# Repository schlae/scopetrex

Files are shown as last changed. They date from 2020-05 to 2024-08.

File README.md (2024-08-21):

# SCOPETREX
## Vector Gaming on Your Oscilloscope!

**Update 21-August-2024: I learned that the IRQ line on the 65C22 wasn't connected, so I fixed that.
See the section at the bottom for details, or just fab with the latest files and don't worry about it.**

Have you ever wanted to buy a Vectrex, but you can't afford the high prices on
auction sites? Do you already have a hoard of Vectrexes, but want *another*
one? Well now you can build your own!

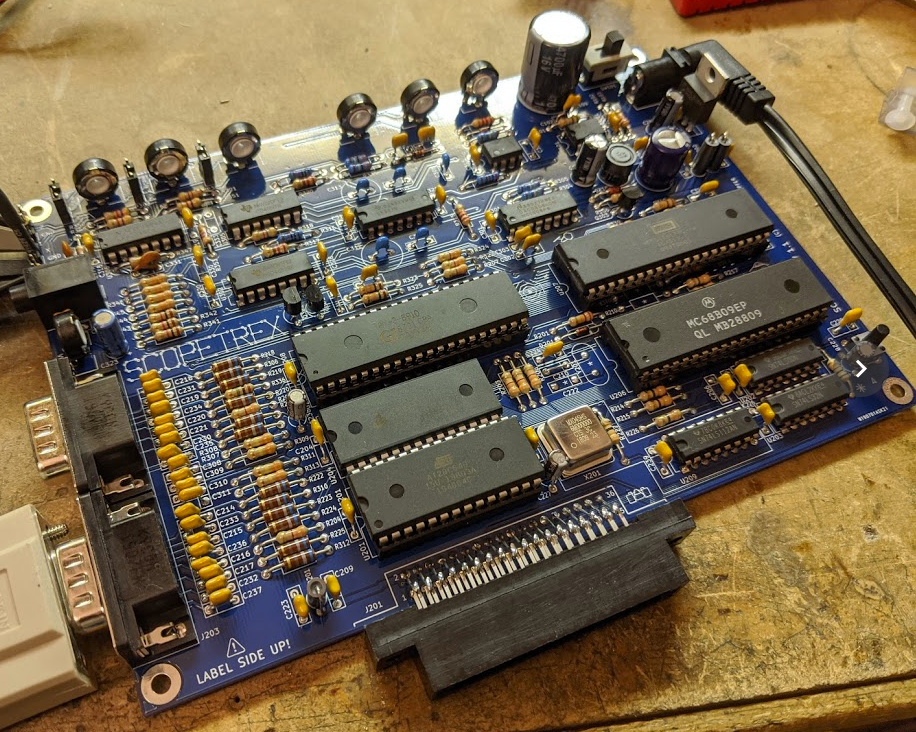
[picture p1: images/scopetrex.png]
SCOPETREX photo


The SCOPETREX is basically a Vectrex on a single board without a monitor.
To play games, you have to connect it to an oscilloscope or an XY monitor.

This board is not just an exact clone of a Vectrex; it makes a number of
improvements over the original.

* Single +5V power supply, only 500mA (minimum)
* Configurable X and Y size and polarity
* Configurable brightness and video blanking polarity
* Works with a 68A09/68B09 or the more common 68A09E/68B09E
* Works with the AY-3-8912 sound chip or the cheaper AY-3-8910/YM2149F
* Custom controller board which is also compatible with the Vectrex
* Cool art on the board

All of the components are readily available, either from Mouser or from
various brokers in China. The bills of materials include Mouser part numbers.

[Here is the schematic](https://github.com/schlae/scopetrex/blob/master/Scopetrex.pdf).

There are two separate bills of materials. One is configured for people who
wish to build their SCOPETREX with the 68A09/68B09 (no suffix option), and
the other is configured for the 68A09E/68B09E (note the **E** suffix). In
general, the **E** suffix is easier to find and it is less likely to be a
counterfeit part. One caution: the 6809 and 6809E (no A or B) chips are only
rated to 1MHz while the SCOPETREX requires 1.5MHz operation.

[Bill of Materials, 6809 (plain) version](https://github.com/schlae/scopetrex/blob/master/Scopetrex_6809.csv)

[Bill of Materials, 6809E version](https://github.com/schlae/scopetrex/blob/master/Scopetrex_6809E.csv)

Please note that the 0.1" header pins are *not* listed on the BOM. They are
just standard breakaway headers. Jumper shunts (you will need three) are also
not listed on the BOM.

The game cartridge slot is designed to be used with the Sullins EBC18DRAS
(listed in the BOM as S3311-ND) but you can also use the EDAC 395-036-520-202
since it is available from Mouser and it may be more convenient to order all
the parts at once. If you do this, you will need to install the EDAC slot
at a right angle and add 18 bodge wires (see the Assembly Notes section).

[Here are the fab files](https://github.com/schlae/scopetrex/blob/master/fab/Scopetrex.zip).

Board dimensions are 7 x 5 inches. Order the board in whatever cool colors
you like!

## The Controller
The SCOPETREX also has a controller.

[Schematic](https://github.com/schlae/scopetrex/blob/master/controller/controller.pdf)

[Bill of Materials](https://github.com/schlae/scopetrex/blob/master/controller/controller.csv)

[Fab files](https://github.com/schlae/scopetrex/blob/master/controller/fab/controller.zip)

The board is 5.8 x 2 inches. It's very simple, so before fabbing it out,
considering going into Kicad and customizing it to your tastes. Add some fancy
silkscreen artwork or whatever you want.

The thumb joystick is listed with a Digi-Key part number since Mouser doesn't
carry it, but you can also get it from [Sparkfun](https://www.sparkfun.com/products/9032). There are similar joysticks sold by a number of different vendors
but this is the only one that's been tested.

There is a slide switch with 4 positions that selects which button (1 through
4) the top hat control triggers (when you push down on the joystick).

## Firmware
The SCOPETREX will run with the standard Vectrex firmware. Just program it
into the flash memory chip (the AT28C64). Note that the "Vectrex BIOS" ROM that
you may find does not include the MINE STORM game. Often, the "MINE STORM" ROM
comes with the BIOS so you should use that instead. I will not tell you where
to get ROMs, nor will I send you any. You could go buy a broken Vectrex and
transplant the ROM from that.

## Assembly Notes

In general it is a good idea to socket the chips that are hard to find and
thus may be counterfeit. It makes troubleshooting much easier. Therefore,
consider socketing the 6809, the 65C22, and the AY-3-8910/12.

The U101/MC34063 power supply chip should be soldered directly to the board
for best performance since a socket adds resistance.

The game cartridge connector has two different part numbers on the BOM. If
you ordered the EDAC part from Mouser which is designed to mount vertically
on the board, you will not be able to plug the cart into it because the case
will bump into components on the board. I recommend rotating the connector
90 degrees and soldering the bottom 18 pins directly to the footprint and
connecting the top 18 pins using bodge wires.

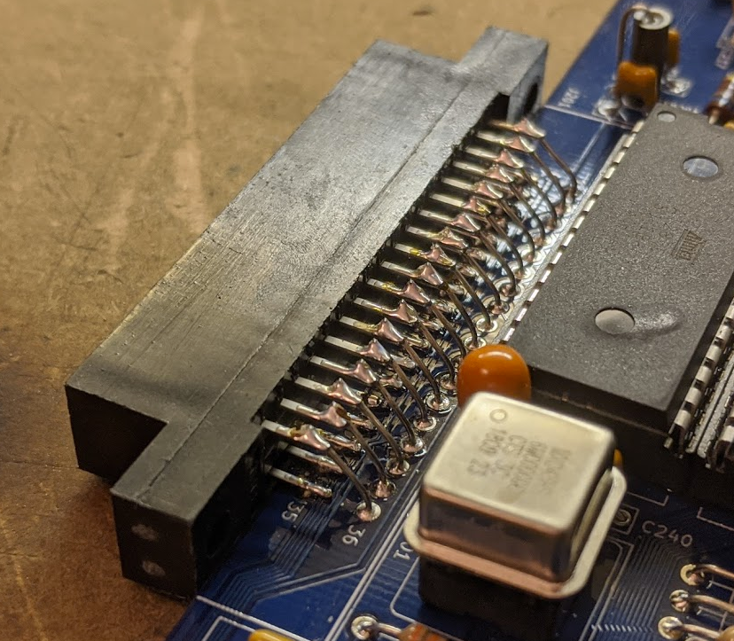
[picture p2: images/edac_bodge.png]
Photo of EDAC connector bodge


Don't forget to install the jumpers J301, J302, and J303. If you aren't sure
what polarity you need, just set them all to "NORM."

Set all the trimmer potentiometers to the halfway position. You'll tune them
later on.

Don't forget to flash the firmware into the AT28C64. There are many devices
that can do this. I like the MINIPRO programmers that are available cheaply
from many different sources.

When you assemble the controller board, be sure to install the DE-9 connector
on the bottom of the circuit board rather than the top.

## Initial Powerup and Calibration
You can connect your oscilloscope probes to the X, Y, and Z (aka blanking)
directly or by making up adapter BNC cables that go directly into your
oscilloscope or XY monitor inputs.

To start with, connect just the X and Y outputs to your oscilloscope's channel
1 and channel 2 inputs. Set both channels to 1V/div and put the oscilloscope
into XY mode (on some oscilloscopes, you do this by rotating the horizontal
sweep rate knob all the way counterclockwise).

**Be very careful about setting the brightness/intensity control on your
oscilloscope. A spot that is too bright can permanently damage the phosphor
coating inside the CRT, leaving a dark spot!**

Connect a 5V power source to the input jack on the SCOPETREX and move the
power switch to the ON position. After a second you should see lines and dots
appear in various places on the oscilloscope. You may have to adjust the
intensity knob to be able to see them.

Next, connect the oscilloscope's Z axis input (sometimes called video or
blanking) to the Z axis output of the SCOPETREX. Try adjusting the brightness
trimmer on the SCOPETREX. If you still see a lot of lines and a bright spot
in the middle of the screen, switch the polarity jumper on the Z axis (JP301).
Adjust the brightness trimmer again until the spot in the center goes away.

At this point you can also plug in a controller and some speakers into the
audio jack. Make sure you can get sound, and check if the controller works.

The SCOPETREX requires some calibration to be performed to get the best image
quality. To do this, you will need a Vectrex test cart (often included in
multicarts, which you probably want to have anyway.)

The first step of calibration involves correcting the DAC offset voltage. With
the test cart installed (no hot swapping carts! label side up!) you will first
see a grid displayed on the screen. Hit button 4, and the display should read
"DAC OFFSET," slowly blinking on and off. Connect a voltmeter between ground
(I like the convenient mounting holes in the corners of the board) and the left
side of R303 (marked with an arrow on the board). This is the voltage output,
pin 1, of the U304 op amp. With the text *off*, the voltmeter should read 0V.
If not, adjust the DAC offset trimmer until you get the voltage to 0V.

The second step involves fixing the X and Y adjustments. You can do this with
the test cart's third screen by pressing button 4 again. You'll see some
diamond-shaped targets; adjust X and Y so that the vertical and horizontal
lines are center inside the diamond shapes.

The third step is less specific, try hitting buttons 3 and 4 to switch to
various screens. Adjust the X and Y as you like to get things to look good.

The final step is the joystick calibration. Go to the last screen--the one
that you can't seem to exit by pushing a button--and adjust the two trimmers
on the *controller board* until the line segment turns into a dot. Swirl the
joystick around to make sure it hits all the square boxes. To exit this screen,
you have to push buttons 1 and 3 or buttons 1 and 4 at the same time.

## XY Monitors

XY monitors such as the Tektronix 602 or 604 offer a nicer experience for
playing Vectrex games. Typically they have a fixed analog deflection voltage of
only a volt or two, so you will need to use the width and height trimmers to
dial back the deflection so that all the objects are on the screen.

Pro tip--turn a landscape-mode XY monitor up on its side and swap the X and Y
inputs to mimic the Vectrex's portrait orientation.

## Troubleshooting
The SCOPETREX is a fairly complex mixed-signal board. I can't tell you all the
possible ways it can go wrong, but here's a list of things to check...
* Power supply voltages: Are +5V, -5V, and the -12V rails all present?
* Reset signal: Does the reset input on the 6809 go high?
* Does the 6809 have a valid set of clock signals? Check E and Q, and the
crystal or oscillator
* Is there activity on the bus? Check the address and data lines
* Does the ROM chip ever get selected? Both the CS# and OE# lines must be
pulsing for that to happen. How about the RAM chip?
* Check for activity on the 65C22 outputs
* Does sound come out of the AY-3-8910/2?
* Look at the waveform on pin 1 of U304A. You should see a fairly complex
waveform
* The SCOPETREX works by using a constant voltage into an integrator to
generate ramps that drive the X and Y deflection signals. Work your way back
along the analog signal chain starting from the individual deflection outputs
* Take a look at the blanking signal (Z axis) output magnitudes. You might
want to check the manual for your oscilloscope to find out the acceptable range
of voltages

## The IRQ Line Bug

Lately it came to my attention that there was a bug in the earlier version of
the board, but nobody actually reported it to me! Fortunately it is a very
easy issue to fix. If you fab your boards from the latest version of the files
in this repository (21-August-2024 or later) then this issue has been fixed.

If you have an older board, you can correct the problem by running a wire from
U207 pin 21 (the 65C22) and U206 pin 3.

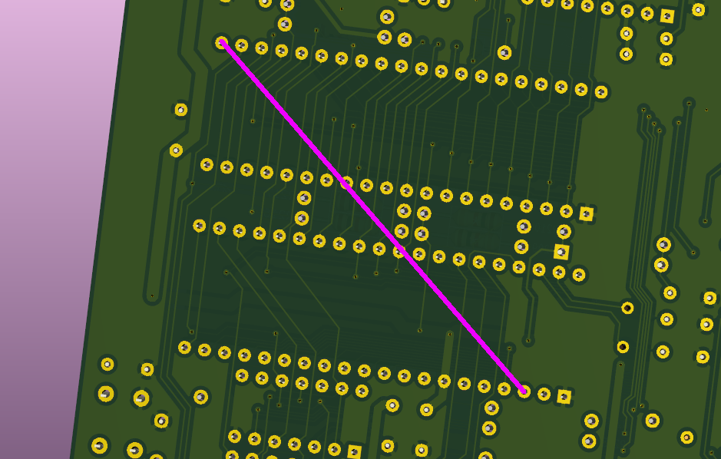
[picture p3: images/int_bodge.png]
Diagram showing which pins to connect


## Other Notes

After all that work, don't forget to enjoy playing some Vectrex games!

## License
This work is licensed under a Creative Commons Attribution-ShareAlike 4.0
International License. See [https://creativecommons.org/licenses/by-sa/4.0/](https://creativecommons.org/licenses/by-sa/4.0/).

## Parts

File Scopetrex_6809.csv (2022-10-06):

Item | Qty | Reference(s) | Value | Digikey | Mouser
1 | 19 | C101, C214, C215, C216, C217, C218, C219, C220, C221, C230, C231, C232, C233, C307, C308, C309, C310, C311, C330 | 1000pF |  | 581-SR211A102JAR
2 | 32 | C102, C103, C110, C111, C201, C204, C206, C207, C208, C209, C211, C223, C224, C225, C226, C234, C235, C236, C237, C301, C302, C314, C316, C317, C318, C319, C320, C321, C324, C326, C327, C328 | 0.1uF |  | 581-SR215C104K
3 | 1 | C104 | 470uF |  | 80-ESL477M025AH9AA
4 | 1 | C109 | 4700uF |  | 667-EEU-FS1C472S
5 | 1 | C122 | 220uF |  | 647-UVY1E221MED1TD
6 | 2 | C210, C222 | 20pF |  | 581-SR215A220KARTR1
7 | 1 | C213 | 100uF |  | 647-UVY1E101MDD1TD
8 | 3 | C227, C228, C238 | 22uF |  | 647-UPW1A220MDD6TP
9 | 1 | C229 | 0.01uF |  | 581-SR211C103KARTR1
10 | 2 | C239, C240 | DNI
11 | 4 | C303, C315, C331, C332 | 47pF |  | 581-SR211A470JAR
12 | 3 | C304, C305, C306 | 4700pF |  | 810-FG28C0G2A472JRT6
13 | 2 | C312, C313 | 0.01uF |  | 810-FG28C0G2A103JRT6
14 | 1 | C323 | 4.7uF 16V |  | 647-UKT1E4R7MDD1TD
15 | 1 | C325 | 220pF |  | 581-SR211A221JAATR
16 | 1 | C333 | DNI
17 | 1 | D101 | 1N5819 |  | 511-1N5819
18 | 3 | D201, D301, D302 | 1N4148 |  | 512-1N4148
19 | 1 | DZ102 | 13V 400mW |  | 512-1N4743ATR
20 | 3 | FB201, FB202, FB203 | 96Ω @ 25MHz |  | 623-2743007112
21 | 1 | J101 | 5V INPUT |  | 490-PJ-002B
22 | 1 | J201 | CART | A139219-ND | 587-395-036
23 | 1 | J202 | LEFT JOYSTICK |  | 806-K22X-E9P-N
24 | 1 | J203 | RIGHT JOYSTICK |  | 806-K22X-E9P-N
25 | 1 | J301 | Z
26 | 1 | J302 | SJ1-353XN |  | 490-SJ1-3533NG
27 | 1 | J303 | X
28 | 1 | J304 | Y
29 | 1 | JP301 | Z POL
30 | 1 | JP302 | Y POL
31 | 1 | JP303 | X POL
32 | 1 | L101 | 220uH |  | 851-RCR875DNP-221K
33 | 4 | MNT1, MNT2, MNT3, MNT4 | MountingHole_Pad
34 | 2 | Q301, Q302 | 2N3906 |  | 512-2N3906TA
35 | 1 | Q303 | 2N3904 |  | 512-2N3904TA
36 | 1 | R101 | 0.5 |  | 660-CF1/4CR50J
37 | 3 | R102, R314, R315 | 2.2K |  | 603-CFR-25JR-522K2
38 | 2 | R103, R201 | 22K |  | 603-CFR-25JR-5222K
39 | 2 | R106, R208 | 100 |  | 603-CFR-25JR-52100R
40 | 10 | R202, R203, R204, R205, R206, R207, R209, R210, R322, R324 | 3.3K |  | 603-CFR-25JR-523K3
41 | 5 | R214, R215, R216, R217, R226 | 33 |  | 603-CFR-25JR-5233R
42 | 12 | R218, R219, R220, R221, R222, R223, R224, R225, R306, R308, R310, R312 | 680 |  | 603-CFR-25JR-52-680R
43 | 1 | R227 | DNI
44 | 3 | R301, R304, R305 | 2.49K 1% |  | 603-MFR-25FRF522K49
45 | 1 | R302 | 5K |  | 531-PT10H-5K-S
46 | 1 | R303 | 2.61K 1% |  | 603-MFR-25FRF52-2K61
47 | 4 | R307, R309, R311, R313 | 330K |  | 603-CFR-25JR-52-330K
48 | 2 | R316, R319 | 10K 1% |  | 603-MFR-25FRF5210K
49 | 2 | R317, R320 | 220 |  | 603-CFR-25JR-52220R
50 | 10 | R318, R321, R338, R339, R347, R348, R349, R350, R351, R353 | 4.7K |  | 603-CFR-25JR-524K7
51 | 2 | R323, R325 | 15K |  | 603-CFR-25JR-5215K
52 | 6 | R326, R333, R335, R352, R354, R355 | 10K |  | 531-PT10H-10K-S
53 | 4 | R327, R344, R345, R346 | 33K |  | 603-CFR-25JR-52-33K
54 | 2 | R332, R334 | 3.3M |  | 603-MFR-25FTE52-3M3
55 | 1 | R336 | 1M |  | 603-CFR-25JR-521M
56 | 1 | R340 | 10K |  | 603-CFR-25JR-5210K
57 | 3 | R341, R342, R343 | 1K |  | 603-CFR-25JR-521K
58 | 1 | SW101 | POWER |  | 633-CS12ANW03
59 | 1 | SW201 | SW_TACT |  | 612-TL1105B
60 | 1 | U101 | MC34063EBN |  | 511-MC34063EBN
61 | 1 | U102 | LM7905_TO220 |  | 926-LM7905CT/NOPB
62 | 1 | U201 | AT28C64B |  | 556-AT28C64B15PU
63 | 1 | U202 | 74LS00 |  | 595-SN74LS00N
64 | 1 | U203 | 74LS32 |  | 595-SN74LS32N
65 | 1 | U204 | AS6C62256 |  | 913-AS6C62256-55PCN
66 | 1 | U205 | AY3-8910
67 | 1 | U206 | MC68A09 or MC68B09
68 | 1 | U207 | W65C22S6TPG |  | 955-W65C22S6TPG-14
69 | 1 | U208 | AY3-8912
70 | 1 | U209 | DNI
71 | 1 | U301 | MC1408_DIP |  | 926-DAC0808LCN/NOPB
72 | 1 | U302 | CD4052B |  | 595-CD4052BE
73 | 1 | U303 | LF347 |  | 595-LF347N
74 | 1 | U304 | LF353 |  | 595-LF353P
75 | 1 | U305 | 4066 |  | 595-CD4066BE
76 | 1 | U306 | LM6134 |  | 926-LM6134BIN/NOPB
77 | 1 | X201 | DNI
78 | 1 | Y201 | 6MHz |  | 815-AB-6-B2

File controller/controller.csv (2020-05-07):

Item | Qty | Reference(s) | Value | Digikey | Mouser
1 | 1 | J1 | TO VECTREX |  | 806-K22X-E9S-NR
2 | 1 | J2 | JOYSTICK_COM-09032 | 1568-1526-ND
3 | 2 | R1, R3 | 2.2K |  | 603-CFR-25JR-522K2
4 | 2 | R2, R4 | 10K |  | 531-PT10LV113A22PMS
5 | 4 | SW1, SW2, SW3, SW4 | SW_TACT |  | 688-SKHCBKA010
6 | 1 | SW5 | TOP_HAT_SEL |  | 611-SK-14D01-G6

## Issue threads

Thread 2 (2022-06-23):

Distorted image

VectorFever, 2022-06-23:
Hello! You have created a masterpiece! But I have issues with it. I want to build my own Vectrex with electromagnetic crt with audio amplifier like in your CRT-Driver project. It works decent, but not with Scopetrex. Digital part of Scopetrex works good but analog is messed. I also tried it on oscilloscope but it was looking just the same. DAC adjust does not help.All components are same but 4700pf capacitors were changed with 0.01μF ones like in original Vectrex schematic. Replacing them with lower values seems doesn't doing too much. I guess the problem in op amps. I used TL072 and TL074 from STM instead of LFs because I couldn't find them. Their electrical characteristics absolutely same but simplified schematic is different. Maybe that's the reason. Can You please try to replace LFs with TLs and say if it's the reason? Thank You for help!

VectorFever, 2022-07-02:
Solved

rothkane, 2024-02-01:
> Solved

How was this solved as I have the same issue with a distorted screen

Closed 2022-07-02.

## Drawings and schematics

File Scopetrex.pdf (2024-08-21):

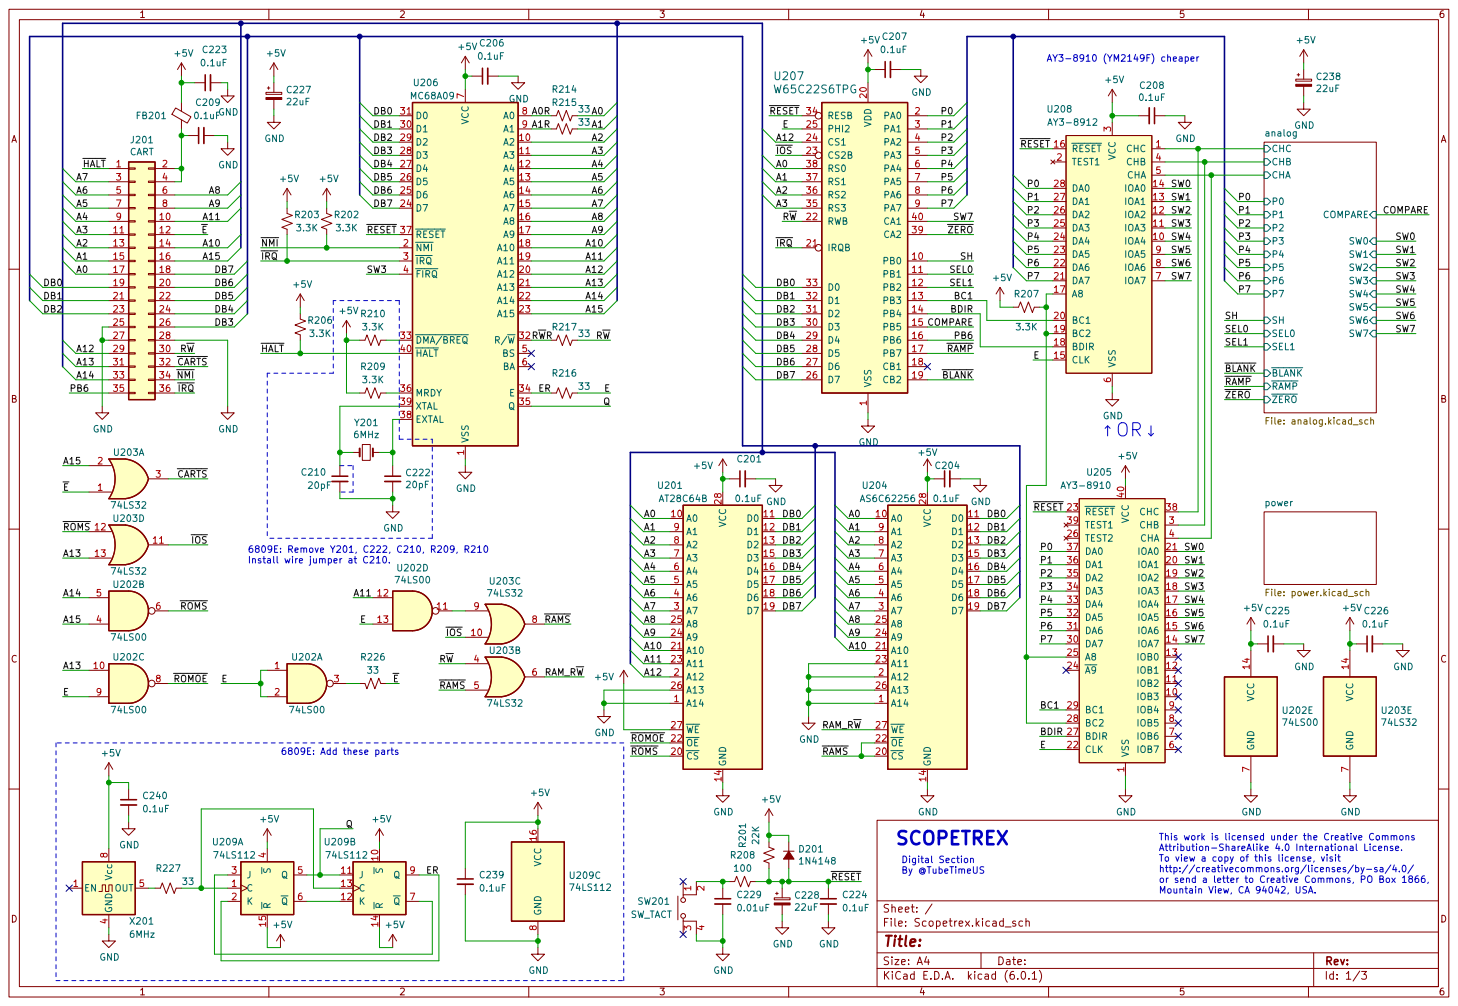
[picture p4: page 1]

1 A2 10 A3 11 A4 12 A5 13 A6 14 A7 15 A8 16 A9 17 A10 18 A11 19 ~{NMI} 2 A12 20 A13 21 A14 22 A15 23 D7 24 D6 25 D5 26 D4 27 D3 28 D2 29 ~{IRQ} 3 D1 30 D0 31 R/~{W}32 ~{DMA/BREQ} 33 E

http://creativecommons.org/licenses/by-sa/4.0/ or send a letter to Creative Commons, PO Box 1866, Mountain View, CA 94042, USA. þÿ!‘OR!“

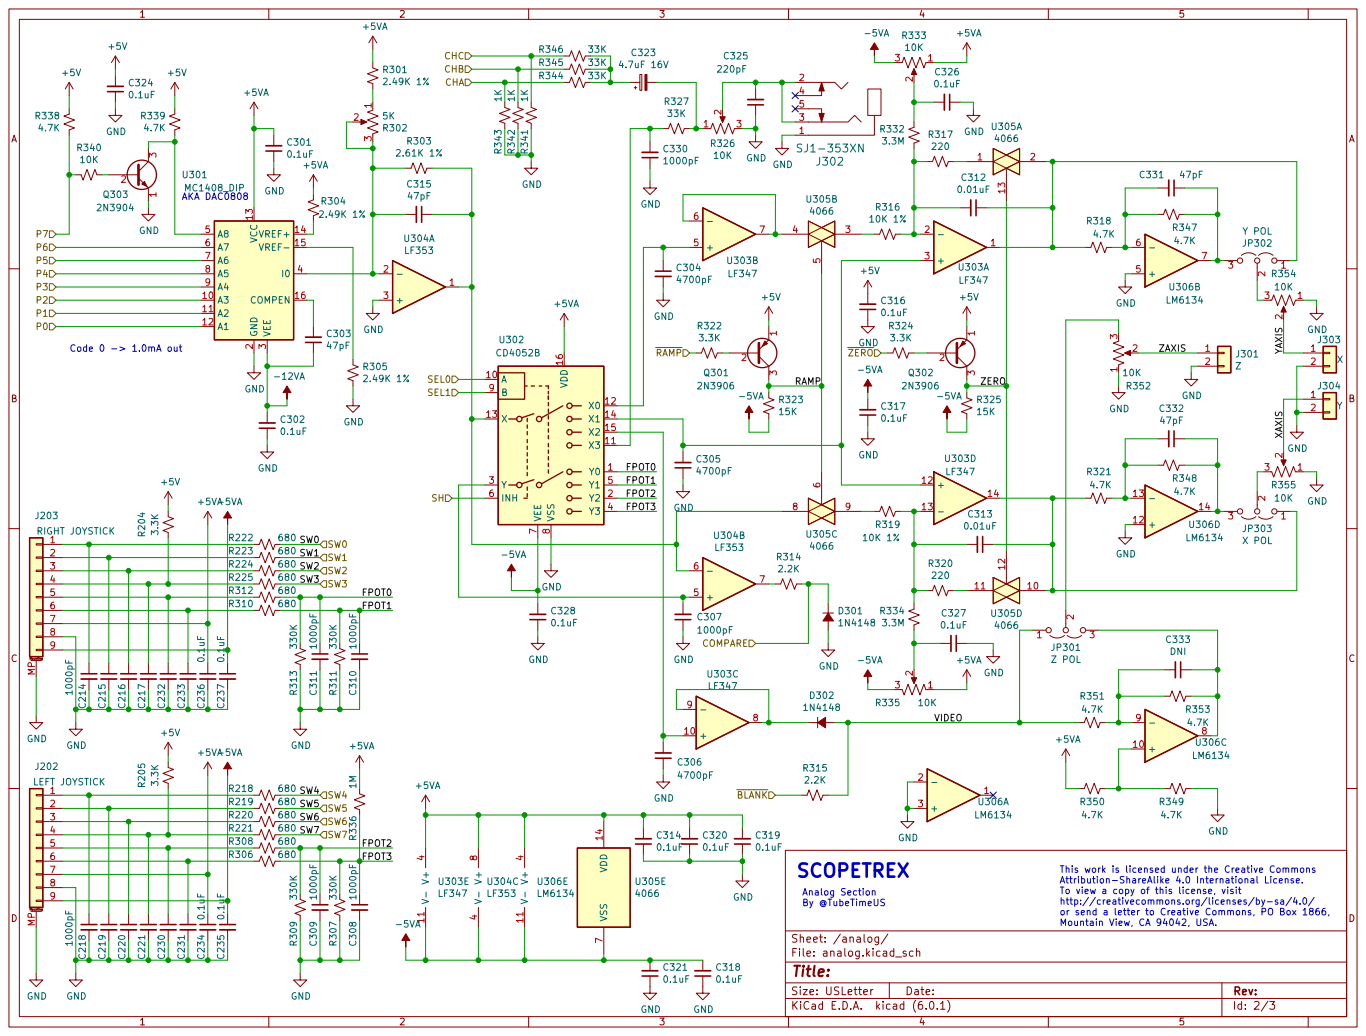
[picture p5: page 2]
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

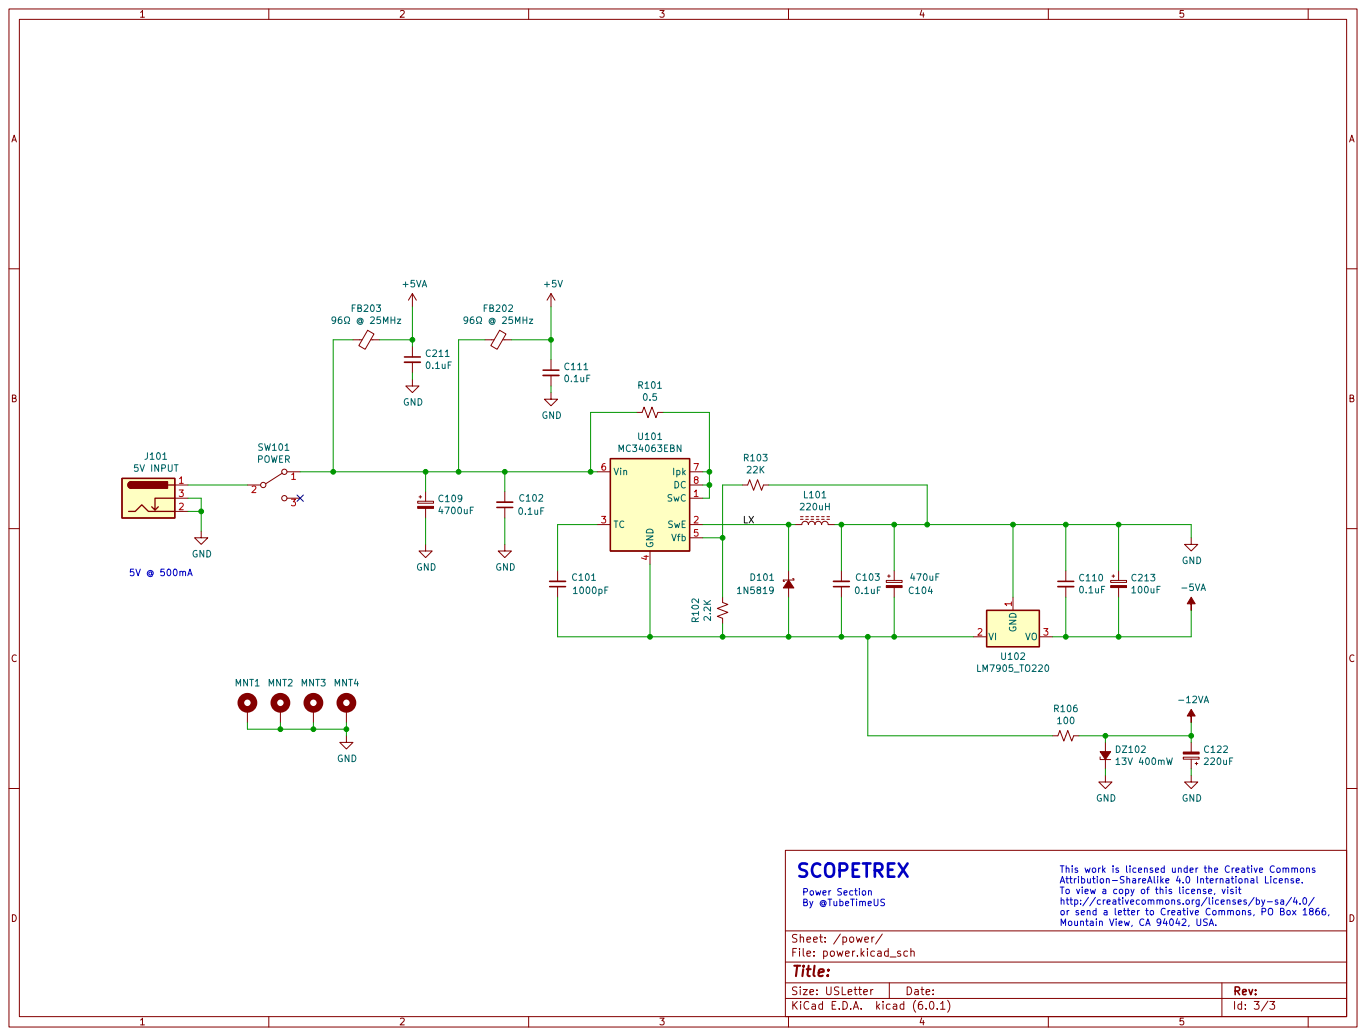
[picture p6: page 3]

http://creativecommons.org/licenses/by-sa/4.0/ or send a letter to Creative Commons, PO Box 1866, Mountain View, CA 94042, USA. SCOPETREX

This work is licensed under the Creative Commons Attribution-ShareAlike 4.0 International License. To view a copy of this license, visit

Power Section By @TubeTimeUS

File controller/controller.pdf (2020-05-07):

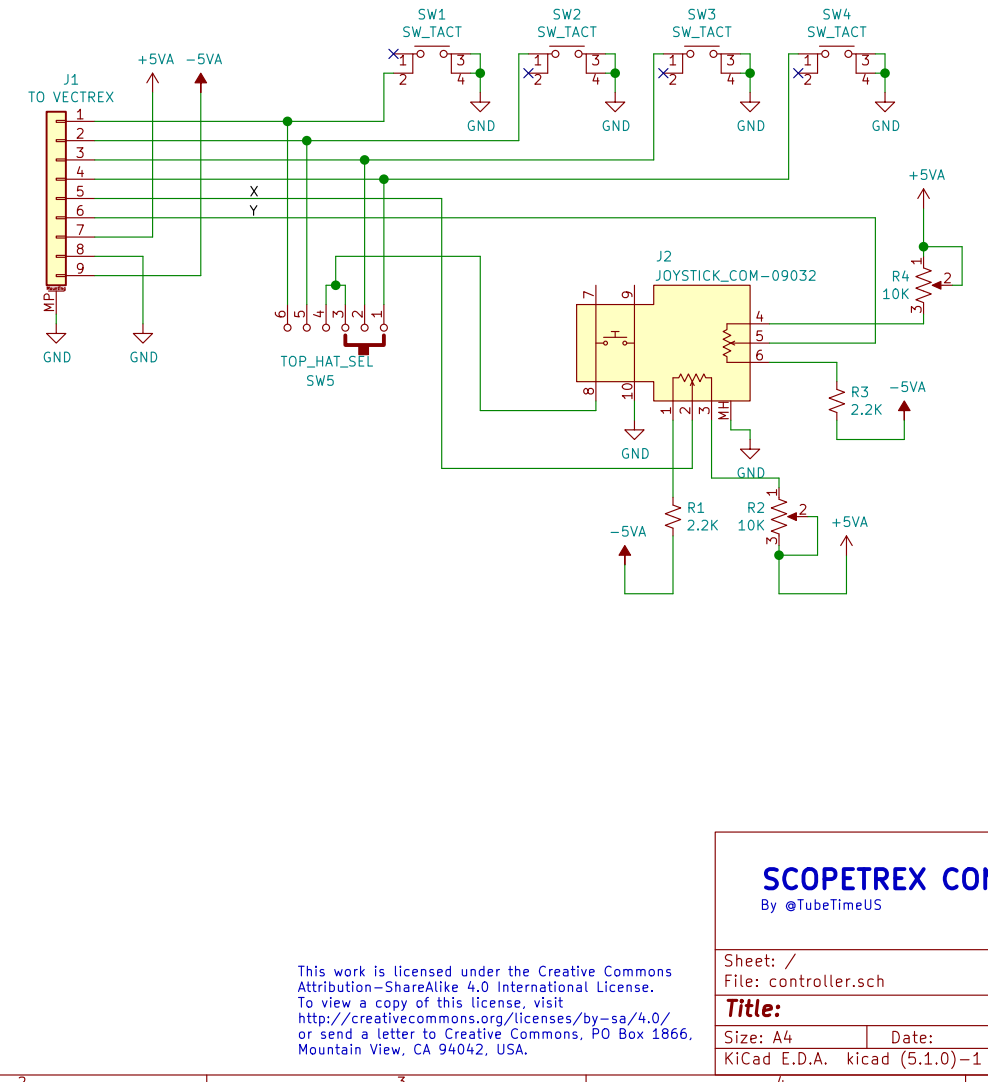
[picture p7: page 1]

1 SW5 TOP_HAT_SEL This work is licensed under the Creative Commons Attribution-ShareAlike 4.0 International License. To view a copy of this license, visit

Id: 1/1 Title: File: controller.sch Sheet: /

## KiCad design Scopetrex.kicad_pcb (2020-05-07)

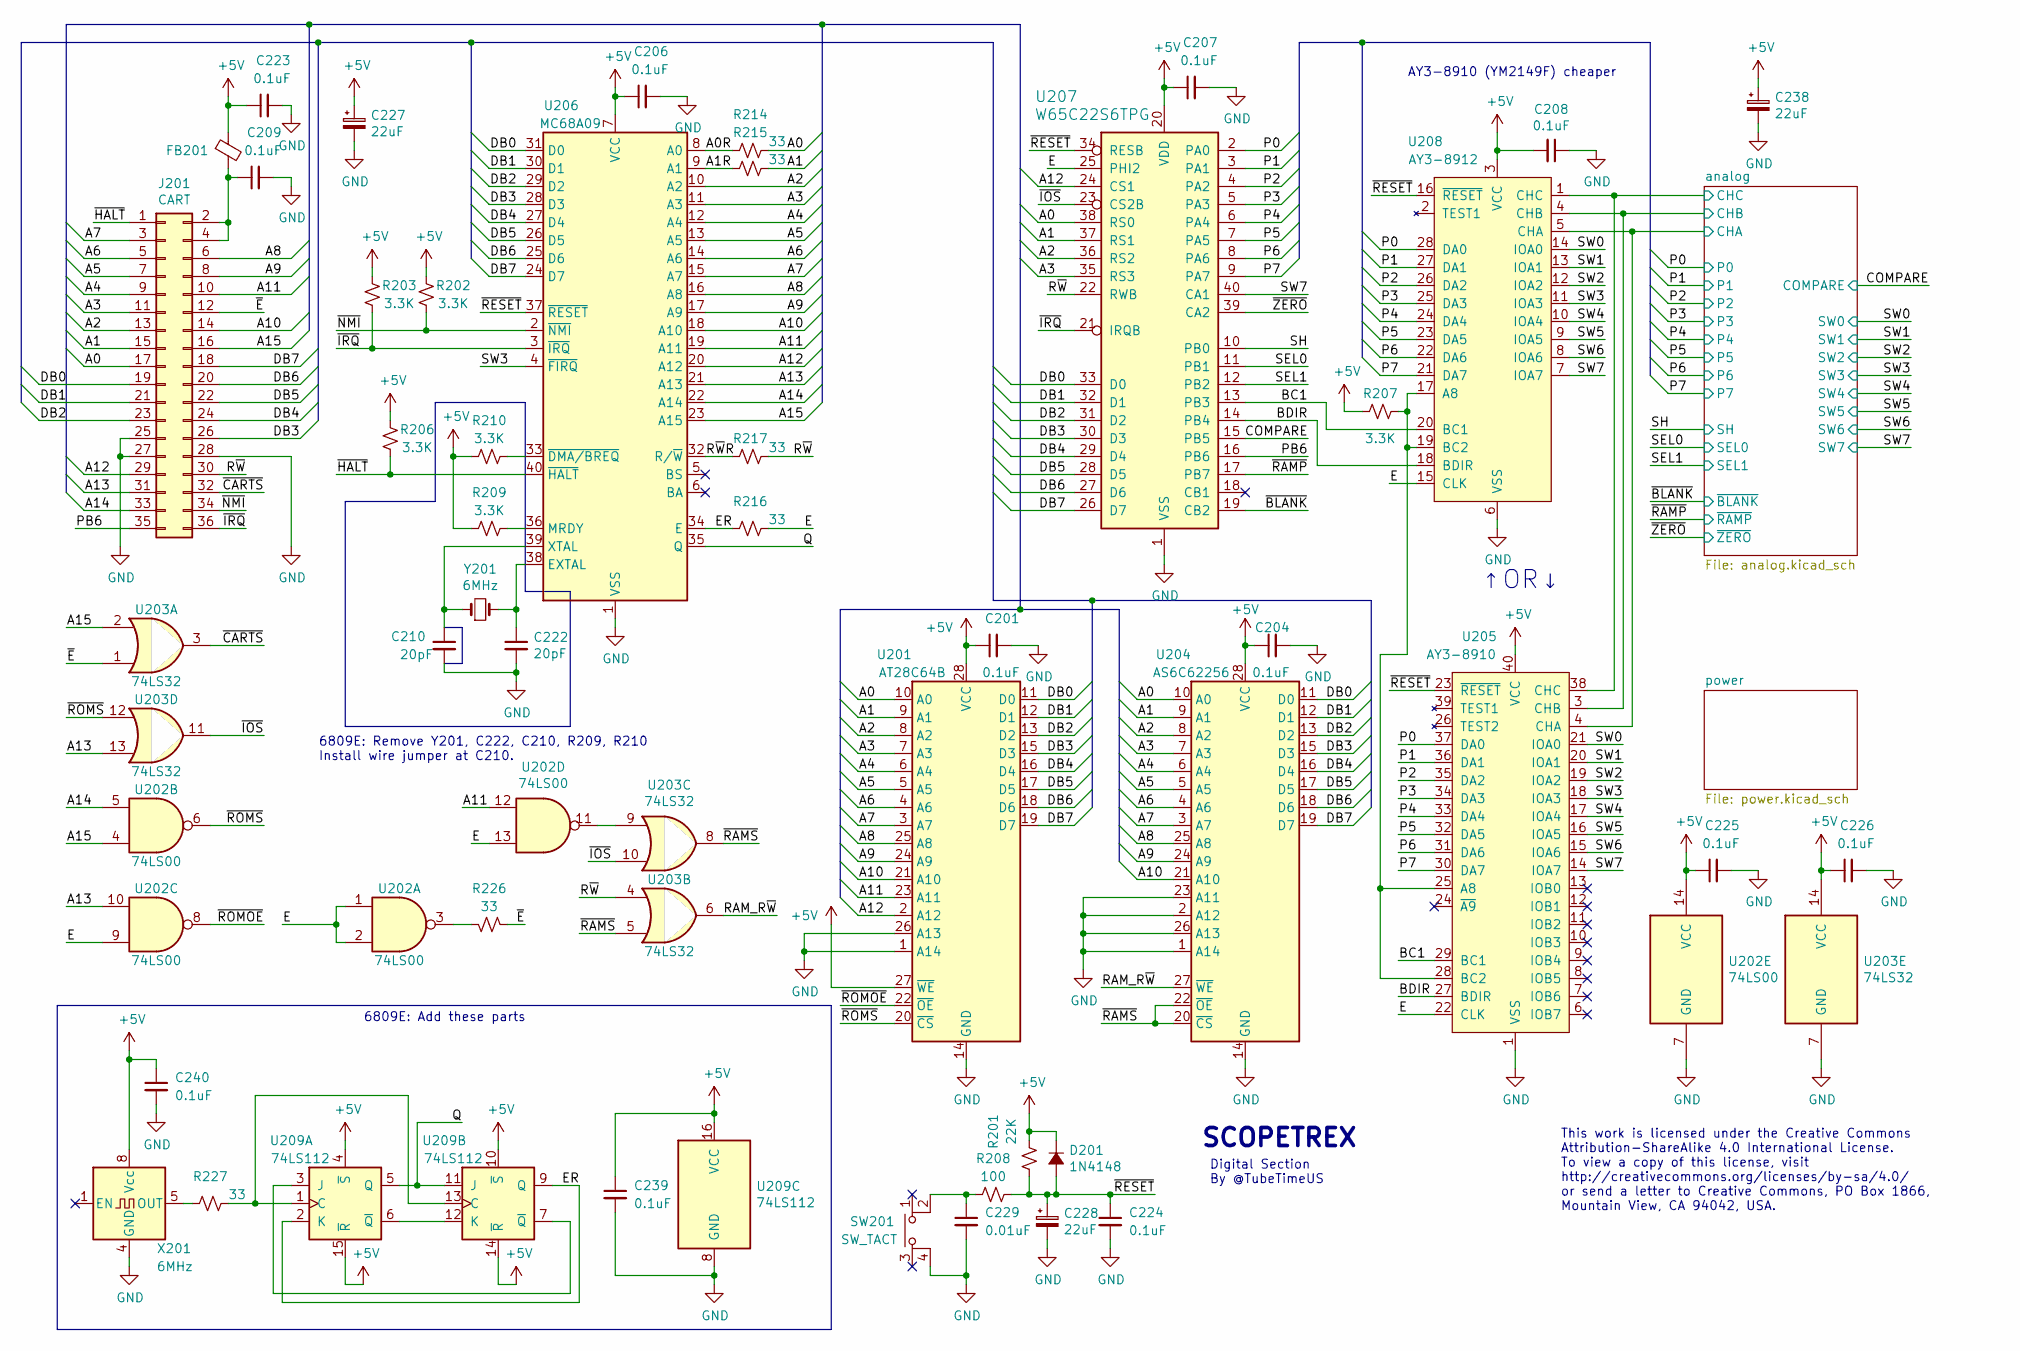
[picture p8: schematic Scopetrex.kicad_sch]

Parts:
C201, C204, C206, C207, C208, C209, C223, C224, C225, C226, C239, C240: 0.1uF; C_Disc_D0.2in_W0.1in_P0.2in; Mouser 581-SR215C104K
C210, C222: 20pF; C_Disc_D0.2in_W0.1in_P0.2in; Mouser 581-SR215A220KARTR1
C227, C228, C238: 22uF; CAPAP200; Mouser 647-UPW1A220MDD6TP
C229: 0.01uF; C_Disc_D0.2in_W0.1in_P0.2in; Mouser 581-SR211C103KARTR1
D201: 1N4148; DIOA500; Mouser 512-1N4148
FB201: 96Ω @ 25MHz; FB254; Mouser 623-2743007112
J201: CART; SULLINS_EBC18DRAS; Mouser 587-395-036
R201: 22K; RESA500; Mouser 603-CFR-25JR-5222K
R202, R203, R206, R207, R209, R210: 3.3K; RESA500; Mouser 603-CFR-25JR-523K3
R208: 100; RESA500; Mouser 603-CFR-25JR-52100R
R214, R215, R216, R217, R226, R227: 33; RESA500; Mouser 603-CFR-25JR-5233R
SW201: SW_TACT; ESWITCH_TL1105; Mouser 612-TL1105B
U201: AT28C64B; DIP254P1524X635-28; Mouser 556-AT28C64B15PU
U202: 74LS00; DIP254P762X635-14; Mouser 595-SN74LS00N
U203: 74LS32; DIP254P762X635-14; Mouser 595-SN74LS32N
U204: AS6C62256; DIP254P1524X635-28; Mouser 913-AS6C62256-55PCN
U205: AY3-8910; DIP254P1524X635-40
U206: MC68A09; DIP254P1524X635-40
U207: W65C22S6TPG; DIP254P1524X635-40; Mouser 955-W65C22S6TPG-14
U208: AY3-8912; DIP254P1524X635-28
U209: 74LS112; DIP254P762X635-16; Mouser 595-SN74LS112AN
X201: 6MHz; Oscillator_DIP-8; Mouser 774-MXO45HS-3C-6.0
Y201: 6MHz; Crystal_HC49-4H_Vertical; Mouser 815-AB-6-B2

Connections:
+5V: C201.1, C204.1, C206.1, C207.1, C208.2, C223.1, C225.1, C226.1, C227.1, C238.1, C239.1, C240.1, D201.1 (K), FB201.1, R201.1, R202.2, R203.2, R206.2, R207.2, R209.1, R210.2, U201.27 (~WE), U201.28 (VCC), U202.14 (VCC), U203.14 (VCC), U204.28 (VCC), U205.40 (VCC), U206.7 (VCC), U207.20 (VDD), U208.3 (VCC), U209.4 (~S), U209.10 (~S), U209.14 (~R), U209.15 (~R), U209.16 (VCC), X201.8 (Vcc); also elsewhere on the board
/A0: J201.17, R214.1, U201.10 (A0), U204.10 (A0), U207.38 (RS0)
/A0R: R214.2, U206.8 (A0)
/A1: J201.15, R215.1, U201.9 (A1), U204.9 (A1), U207.37 (RS1)
/A1R: R215.2, U206.9 (A1)
/A2: J201.13, U201.8 (A2), U204.8 (A2), U206.10 (A2), U207.36 (RS2)
/A3: J201.11, U201.7 (A3), U204.7 (A3), U206.11 (A3), U207.35 (RS3)
/A4: J201.9, U201.6 (A4), U204.6 (A4), U206.12 (A4)
/A5: J201.7, U201.5 (A5), U204.5 (A5), U206.13 (A5)
/A6: J201.5, U201.4 (A6), U204.4 (A6), U206.14 (A6)
/A7: J201.3, U201.3 (A7), U204.3 (A7), U206.15 (A7)
/A8: J201.6, U201.25 (A8), U204.25 (A8), U206.16 (A8)
/A9: J201.8, U201.24 (A9), U204.24 (A9), U206.17 (A9)
/A10: J201.14, U201.21 (A10), U204.21 (A10), U206.18 (A10)
/A11: J201.10, U201.23 (A11), U202.12, U206.19 (A11)
/A12: J201.29, U201.2 (A12), U206.20 (A12), U207.24 (CS1)
/A13: J201.31, U202.10, U203.13, U206.21 (A13)
/A14: J201.33, U202.5, U206.22 (A14)
/A15: J201.16, U202.4, U203.2, U206.23 (A15)
/BC1: U205.29 (BC1), U207.13 (PB3), U208.20 (BC1)
/BDIR: U205.27 (BDIR), U207.14 (PB4), U208.18 (BDIR)
/COMPARE: U207.15 (PB5); also elsewhere on the board
/DB0: J201.19, U201.11 (D0), U204.11 (D0), U206.31 (D0), U207.33 (D0)
/DB1: J201.21, U201.12 (D1), U204.12 (D1), U206.30 (D1), U207.32 (D1)
/DB2: J201.23, U201.13 (D2), U204.13 (D2), U206.29 (D2), U207.31 (D2)
/DB3: J201.26, U201.15 (D3), U204.15 (D3), U206.28 (D3), U207.30 (D3)
/DB4: J201.24, U201.16 (D4), U204.16 (D4), U206.27 (D4), U207.29 (D4)
/DB5: J201.22, U201.17 (D5), U204.17 (D5), U206.26 (D5), U207.28 (D5)
/DB6: J201.20, U201.18 (D6), U204.18 (D6), U206.25 (D6), U207.27 (D6)
/DB7: J201.18, U201.19 (D7), U204.19 (D7), U206.24 (D7), U207.26 (D7)
/E: R216.1, U202.1, U202.2, U202.9, U202.13, U205.22 (CLK), U207.25 (PHI2), U208.15 (CLK)
/ER: R216.2, U206.34 (E), U209.2 (K), U209.9 (Q)
/P0: U205.37 (DA0), U207.2 (PA0), U208.28 (DA0); also elsewhere on the board
/P1: U205.36 (DA1), U207.3 (PA1), U208.27 (DA1); also elsewhere on the board
/P2: U205.35 (DA2), U207.4 (PA2), U208.26 (DA2); also elsewhere on the board
/P3: U205.34 (DA3), U207.5 (PA3), U208.25 (DA3); also elsewhere on the board
/P4: U205.33 (DA4), U207.6 (PA4), U208.24 (DA4); also elsewhere on the board
/P5: U205.32 (DA5), U207.7 (PA5), U208.23 (DA5); also elsewhere on the board
/P6: U205.31 (DA6), U207.8 (PA6), U208.22 (DA6); also elsewhere on the board
/P7: U205.30 (DA7), U207.9 (PA7), U208.21 (DA7); also elsewhere on the board
/PB6: J201.35, U207.16 (PB6)
/Q: U206.35 (Q), U209.5 (Q), U209.11 (J)
/RAM_R~W: U203.6, U204.27 (~WE)
/R~W: J201.30, R217.1, U203.4, U207.22 (RWB)
/R~W~R: R217.2, U206.32 (R/~W)
/SEL0: U207.11 (PB1); also elsewhere on the board
/SEL1: U207.12 (PB2); also elsewhere on the board
/SH: U207.10 (PB0); also elsewhere on the board
/SW0: U205.21 (IOA0), U208.14 (IOA0); also elsewhere on the board
/SW1: U205.20 (IOA1), U208.13 (IOA1); also elsewhere on the board
/SW2: U205.19 (IOA2), U208.12 (IOA2); also elsewhere on the board
/SW3: U205.18 (IOA3), U206.4 (~FIRQ), U208.11 (IOA3); also elsewhere on the board
/SW4: U205.17 (IOA4), U208.10 (IOA4); also elsewhere on the board
/SW5: U205.16 (IOA5), U208.9 (IOA5); also elsewhere on the board
/SW6: U205.15 (IOA6), U208.8 (IOA6); also elsewhere on the board
/SW7: U205.14 (IOA7), U207.40 (CA1), U208.7 (IOA7); also elsewhere on the board
/analog/CHA: U205.4 (CHA), U208.5 (CHA); also elsewhere on the board
/analog/CHB: U205.3 (CHB), U208.4 (CHB); also elsewhere on the board
/analog/CHC: U205.38 (CHC), U208.1 (CHC); also elsewhere on the board
/~BLANK: U207.19 (CB2); also elsewhere on the board
/~CARTS: J201.32, U203.3
/~E: J201.12, R226.2, U203.1
/~HALT: J201.1, R206.1, U206.40 (~HALT)
/~IOS: U203.10, U203.11, U207.23 (CS2B)
/~IRQ: J201.36, R203.1, U206.3 (~IRQ), U207.21 (IRQB)
/~NMI: J201.34, R202.1, U206.2 (~NMI)
/~RAMP: U207.17 (PB7); also elsewhere on the board
/~RAMS: U203.5, U203.8, U204.20 (~CS), U204.22 (~OE)
/~RESET: C224.1, C228.1, D201.2 (A), R201.2, R208.1, U205.23 (~RESET), U206.37 (~RESET), U207.34 (RESB), U208.16 (~RESET)
/~ROMOE: U201.22 (~OE), U202.8
/~ROMS: U201.20 (~CS), U202.6, U203.12
/~ZERO: U207.39 (CA2); also elsewhere on the board
GND: C201.2, C204.2, C206.2, C207.2, C208.1, C209.2, C210.2, C222.2, C223.2, C224.2, C225.2, C226.2, C227.2, C228.2, C229.2, C238.2, C239.2, C240.2, J201.25, J201.27, J201.28, SW201.4, U201.1 (A14), U201.14 (GND), U201.26 (A13), U202.7 (GND), U203.7 (GND), U204.1 (A14), U204.2 (A12), U204.14 (GND), U204.23 (A11), U204.26 (A13), U205.1 (VSS), U206.1 (VSS), U207.1 (VSS), U208.6 (VSS), U209.8 (GND), X201.4 (GND); also elsewhere on the board
unnamed: C209.1, FB201.2, J201.2, J201.4
unnamed: C210.1, U206.39 (XTAL), Y201.1
unnamed: C222.1, U206.38 (EXTAL), Y201.2
unnamed: C229.1, R208.2, SW201.2
unnamed: R207.1, U205.25 (A8), U205.28 (BC2), U208.17 (A8), U208.19 (BC2)
unnamed: R209.2, U206.36 (MRDY)
unnamed: R210.1, U206.33 (~DMA/BREQ)
unnamed: R226.1, U202.3
unnamed: R227.1, U209.1 (C), U209.13 (C)
unnamed: R227.2, X201.5 (OUT)
unnamed: U202.11, U203.9
unnamed: U209.3 (J), U209.7 (~Q)
unnamed: U209.6 (~Q), U209.12 (K)

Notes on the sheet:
6809E: Remove Y201, C222, C210, R209, R210 Install wire jumper at C210.
Digital Section By @TubeTimeUS
SCOPETREX
6809E: Add these parts
↑OR↓
This work is licensed under the Creative Commons Attribution-ShareAlike 4.0 International License. To view a copy of this license, visit http://creativecommons.org/licenses/by-sa/4.0/ or send a letter to Creative Commons, PO Box 1866, Mountain View, CA 94042, USA.
AY3-8910 (YM2149F) cheaper

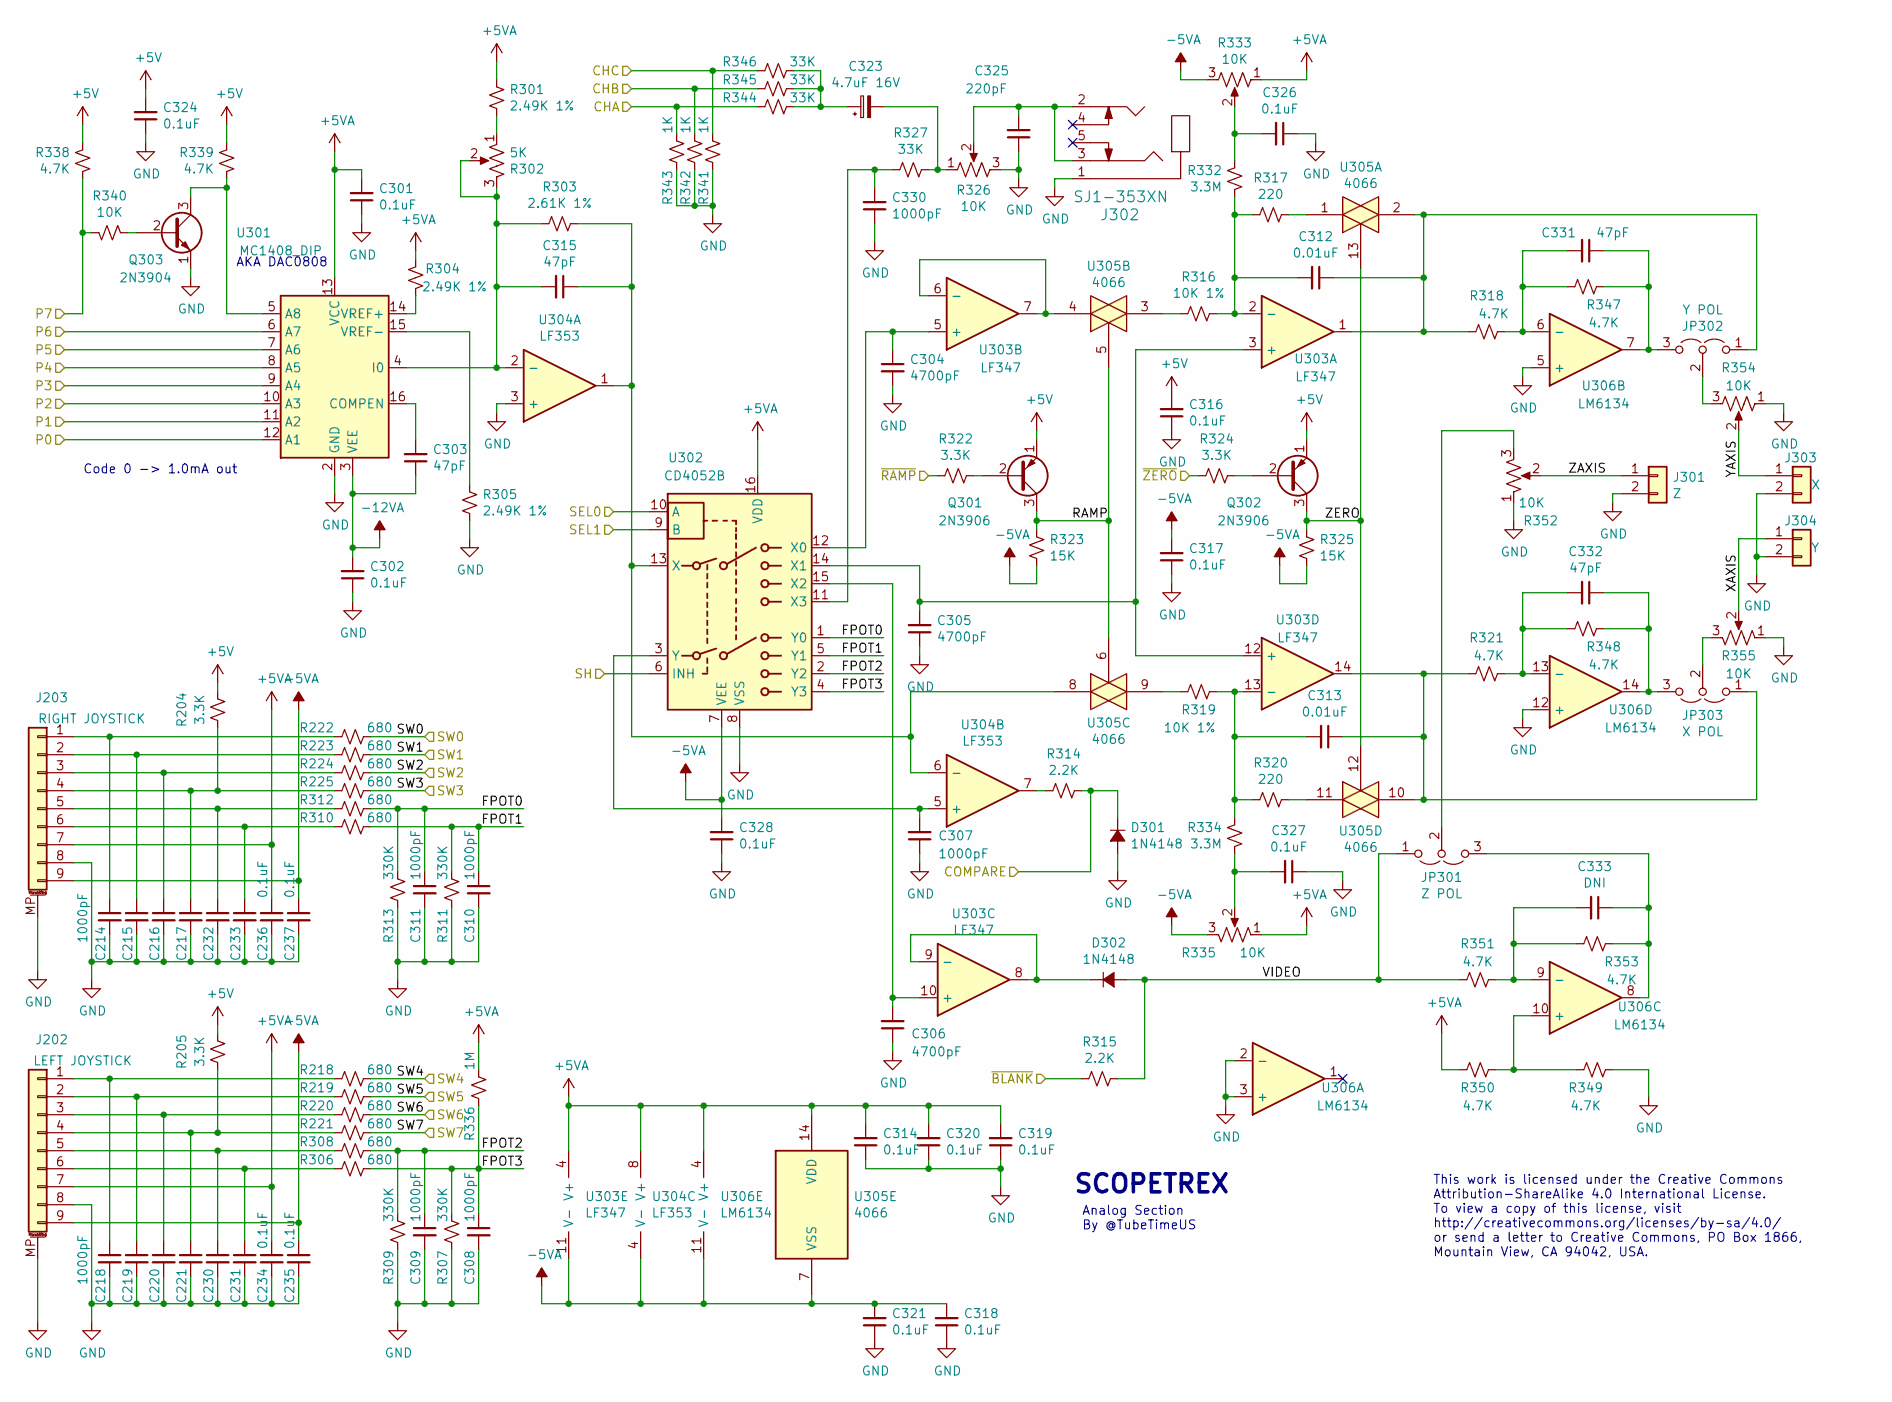
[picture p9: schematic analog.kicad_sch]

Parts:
C214, C215, C216, C217, C218, C219, C220, C221, C230, C231, C232, C233, C307, C308, C309, C310, C311, C330: 1000pF; C_Disc_D0.2in_W0.1in_P0.2in; Mouser 581-SR211A102JAR
C234, C235, C236, C237, C301, C302, C314, C316, C317, C318, C319, C320, C321, C324, C326, C327, C328: 0.1uF; C_Disc_D0.2in_W0.1in_P0.2in; Mouser 581-SR215C104K
C303, C315, C331, C332: 47pF; C_Disc_D0.2in_W0.1in_P0.2in; Mouser 581-SR211A470JAR
C304, C305, C306: 4700pF; C_Disc_D0.2in_W0.1in_P0.2in; Mouser 810-FG28C0G2A472JRT6
C312, C313: 0.01uF; CAPF500P1000X1200; Mouser 810-FG28C0G2A103JRT6
C323: 4.7uF 16V; CAPAE200P500X1100; Mouser 647-UKT1E4R7MDD1TD
C325: 220pF; C_Disc_D0.2in_W0.1in_P0.2in; Mouser 581-SR211A221JAATR
C333: DNI; C_Disc_D0.2in_W0.1in_P0.2in
D301, D302: 1N4148; DIOA500; Mouser 512-1N4148
J202: LEFT JOYSTICK; DB9MC; Mouser 806-K22X-E9P-N
J203: RIGHT JOYSTICK; DB9MC; Mouser 806-K22X-E9P-N
J301: Z; Pin_Header_Straight_1x02_Pitch2.54mm
J302: SJ1-353XN; CUI_SJ1-353XN; Mouser 490-SJ1-3533NG
J303: X; Pin_Header_Straight_1x02_Pitch2.54mm
J304: Y; Pin_Header_Straight_1x02_Pitch2.54mm
JP301: Z POL; Pin_Header_Straight_1x03_Pitch2.54mm
JP302: Y POL; Pin_Header_Straight_1x03_Pitch2.54mm
JP303: X POL; Pin_Header_Straight_1x03_Pitch2.54mm
Q301, Q302: 2N3906; TO92-IL; Mouser 512-2N3906TA
Q303: 2N3904; TO92-IL; Mouser 512-2N3904TA
R204, R205, R322, R324: 3.3K; RESA500; Mouser 603-CFR-25JR-523K3
R218, R219, R220, R221, R222, R223, R224, R225, R306, R308, R310, R312: 680; RESA500; Mouser 603-CFR-25JR-52-680R
R301, R304, R305: 2.49K 1%; RESA500; Mouser 603-MFR-25FRF522K49
R302: 5K; PIHER_PT10_H01; Mouser 531-PT10H-5K-S
R303: 2.61K 1%; RESA500; Mouser 603-MFR-25FRF52-2K61
R307, R309, R311, R313: 330K; RESA500; Mouser 603-CFR-25JR-52-330K
R314, R315: 2.2K; RESA500; Mouser 603-CFR-25JR-522K2
R316, R319: 10K 1%; RESA500; Mouser 603-MFR-25FRF5210K
R317, R320: 220; RESA500; Mouser 603-CFR-25JR-52220R
R318, R321, R338, R339, R347, R348, R349, R350, R351, R353: 4.7K; RESA500; Mouser 603-CFR-25JR-524K7
R323, R325: 15K; RESA500; Mouser 603-CFR-25JR-5215K
R326, R333, R335, R352, R354, R355: 10K; PIHER_PT10_H01; Mouser 531-PT10H-10K-S
R327, R344, R345, R346: 33K; RESA500; Mouser 603-CFR-25JR-52-33K
R332, R334: 3.3M; RESA500; Mouser 603-MFR-25FTE52-3M3
R336: 1M; RESA500; Mouser 603-CFR-25JR-521M
R340: 10K; RESA500; Mouser 603-CFR-25JR-5210K
R341, R342, R343: 1K; RESA500; Mouser 603-CFR-25JR-521K
U301: MC1408_DIP; DIP254P762X635-16; Mouser 926-DAC0808LCN/NOPB
U302: CD4052B; DIP254P762X635-16; Mouser 595-CD4052BE
U303: LF347; DIP254P762X635-14; Mouser 595-LF347N
U304: LF353; DIP254P762X635-8; Mouser 595-LF353P
U305: 4066; DIP254P762X635-14; Mouser 595-CD4066BE
U306: LM6134; DIP254P762X635-14; Mouser 926-LM6134BIN/NOPB

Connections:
+5V: C316.2, C324.2, Q301.1 (E), Q302.1 (E), R204.1, R205.1, R338.2, R339.2; also elsewhere on the board
+5VA: C234.1, C236.1, C301.2, C314.2, C319.2, C320.2, J202.7, J203.7, R301.2, R304.2, R333.1, R335.1, R336.1, R350.2, U301.13 (VCC), U302.16 (VDD), U303.4 (V+), U304.8 (V+), U305.14 (VDD), U306.4 (V+); also elsewhere on the board
-5VA: C235.1, C237.1, C317.2, C318.2, C321.2, C328.2, J202.9, J203.9, R323.2, R325.2, R333.3, R335.3, U302.7 (VEE), U303.11 (V-), U304.4 (V-), U305.7 (VSS), U306.11 (V-); also elsewhere on the board
-12VA: C302.2, C303.1, U301.3 (VEE); also elsewhere on the board
/COMPARE: D301.1 (K), R314.1; also elsewhere on the board
/P0: U301.12 (A1); also elsewhere on the board
/P1: U301.11 (A2); also elsewhere on the board
/P2: U301.10 (A3); also elsewhere on the board
/P3: U301.9 (A4); also elsewhere on the board
/P4: U301.8 (A5); also elsewhere on the board
/P5: U301.7 (A6); also elsewhere on the board
/P6: U301.6 (A7); also elsewhere on the board
/P7: R338.1, R340.1; also elsewhere on the board
/SEL0: U302.10 (A); also elsewhere on the board
/SEL1: U302.9 (B); also elsewhere on the board
/SH: U302.6 (INH); also elsewhere on the board
/SW0: R222.2; also elsewhere on the board
/SW1: R223.2; also elsewhere on the board
/SW2: R224.2; also elsewhere on the board
/SW3: R225.2; also elsewhere on the board
/SW4: R218.2; also elsewhere on the board
/SW5: R219.2; also elsewhere on the board
/SW6: R220.2; also elsewhere on the board
/SW7: R221.2; also elsewhere on the board
/analog/CHA: R343.1, R344.2; also elsewhere on the board
/analog/CHB: R342.1, R345.2; also elsewhere on the board
/analog/CHC: R341.1, R346.2; also elsewhere on the board
/analog/FPOT0: C311.1, R312.2, R313.1, U302.1 (Y0)
/analog/FPOT1: C310.1, R310.2, R311.1, U302.5 (Y1)
/analog/FPOT2: C309.1, R308.2, R309.1, U302.2 (Y2)
/analog/FPOT3: C308.1, R306.2, R307.1, R336.2, U302.4 (Y3)
/analog/RAMP: Q301.3 (C), R323.1, U305.5, U305.6
/analog/VIDEO: D302.2 (A), JP301.1 (A), R315.1, R351.1
/analog/XAXIS: J304.1, R355.2
/analog/YAXIS: J303.1, R354.2
/analog/ZAXIS: J301.1, R352.2
/analog/ZERO: Q302.3 (C), R325.1, U305.12, U305.13
/~BLANK: R315.2; also elsewhere on the board
/~RAMP: R322.2; also elsewhere on the board
/~ZERO: R324.2; also elsewhere on the board
GND: C214.2, C215.2, C216.2, C217.2, C218.2, C219.2, C220.2, C221.2, C230.2, C231.2, C232.2, C233.2, C234.2, C235.2, C236.2, C237.2, C301.1, C302.1, C304.2, C305.1, C306.1, C307.1, C308.2, C309.2, C310.2, C311.2, C314.1, C316.1, C317.1, C318.1, C319.1, C320.1, C321.1, C324.1, C325.1, C326.1, C327.1, C328.1, C330.1, D301.2 (A), J202.8, J202.MP (MountPin), J203.8, J203.MP (MountPin), J301.2, J302.1, J303.2, J304.2, Q303.1 (E), R305.1, R307.2, R309.2, R311.2, R313.2, R326.3, R341.2, R342.2, R343.2, R349.1, R352.1, R354.1, R355.1, U301.2 (GND), U302.8 (VSS), U304.3 (+), U306.2 (-), U306.3 (+), U306.5 (+), U306.12 (+); also elsewhere on the board
unnamed: C214.1, J203.1, R222.1
unnamed: C215.1, J203.2, R223.1
unnamed: C216.1, J203.3, R224.1
unnamed: C217.1, J203.4, R204.2, R225.1
unnamed: C218.1, J202.1, R218.1
unnamed: C219.1, J202.2, R219.1
unnamed: C220.1, J202.3, R220.1
unnamed: C221.1, J202.4, R205.2, R221.1
unnamed: C230.1, J202.5, R308.1
unnamed: C231.1, J202.6, R306.1
unnamed: C232.1, J203.5, R312.1
unnamed: C233.1, J203.6, R310.1
unnamed: C303.2, U301.16 (COMPEN)
unnamed: C304.1, U302.12 (X0), U303.5 (+)
unnamed: C305.2, U302.14 (X1), U303.3 (+), U303.12 (+)
unnamed: C306.2, U302.15 (X2), U303.10 (+)
unnamed: C307.2, U302.3 (Y), U304.5 (+)
unnamed: C312.1, JP302.1 (A), R318.2, U303.1, U305.2
unnamed: C312.2, R316.1, R317.2, R332.1, U303.2 (-)
unnamed: C313.1, JP303.1 (A), R321.1, U303.14, U305.10
unnamed: C313.2, R319.1, R320.2, R334.2, U303.13 (-)
unnamed: C315.1, R303.1, U302.13 (X), U304.1, U304.6 (-), U305.8
unnamed: C315.2, R302.2, R302.3, R303.2, U301.4 (I0), U304.2 (-)
unnamed: C323.1, R344.1, R345.1, R346.1
unnamed: C323.2, R326.1, R327.1
unnamed: C325.2, J302.2, J302.3, R326.2
unnamed: C326.2, R332.2, R333.2
unnamed: C327.2, R334.1, R335.2
unnamed: C330.2, R327.2, U302.11 (X3)
unnamed: C331.1, JP302.3 (B), R347.1, U306.7
unnamed: C331.2, R318.1, R347.2, U306.6 (-)
unnamed: C332.1, JP303.3 (B), R348.2, U306.14
unnamed: C332.2, R321.2, R348.1, U306.13 (-)
unnamed: C333.1, JP301.3 (B), R353.2, U306.8
unnamed: C333.2, R351.2, R353.1, U306.9 (-)
unnamed: D302.1 (K), U303.8, U303.9 (-)
unnamed: JP301.2 (C), R352.3
unnamed: JP302.2 (C), R354.3
unnamed: JP303.2 (C), R355.3
unnamed: Q301.2 (B), R322.1
unnamed: Q302.2 (B), R324.1
unnamed: Q303.2 (B), R340.2
unnamed: Q303.3 (C), R339.1, U301.5 (A8)
unnamed: R301.1, R302.1
unnamed: R304.1, U301.14 (VREF+)
unnamed: R305.2, U301.15 (VREF-)
unnamed: R314.2, U304.7
unnamed: R316.2, U305.3
unnamed: R317.1, U305.1
unnamed: R319.2, U305.9
unnamed: R320.1, U305.11
unnamed: R349.2, R350.1, U306.10 (+)
unnamed: U303.6 (-), U303.7, U305.4

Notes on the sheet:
Analog Section By @TubeTimeUS
AKA DAC0808
Code 0 -> 1.0mA out
SCOPETREX
This work is licensed under the Creative Commons Attribution-ShareAlike 4.0 International License. To view a copy of this license, visit http://creativecommons.org/licenses/by-sa/4.0/ or send a letter to Creative Commons, PO Box 1866, Mountain View, CA 94042, USA.

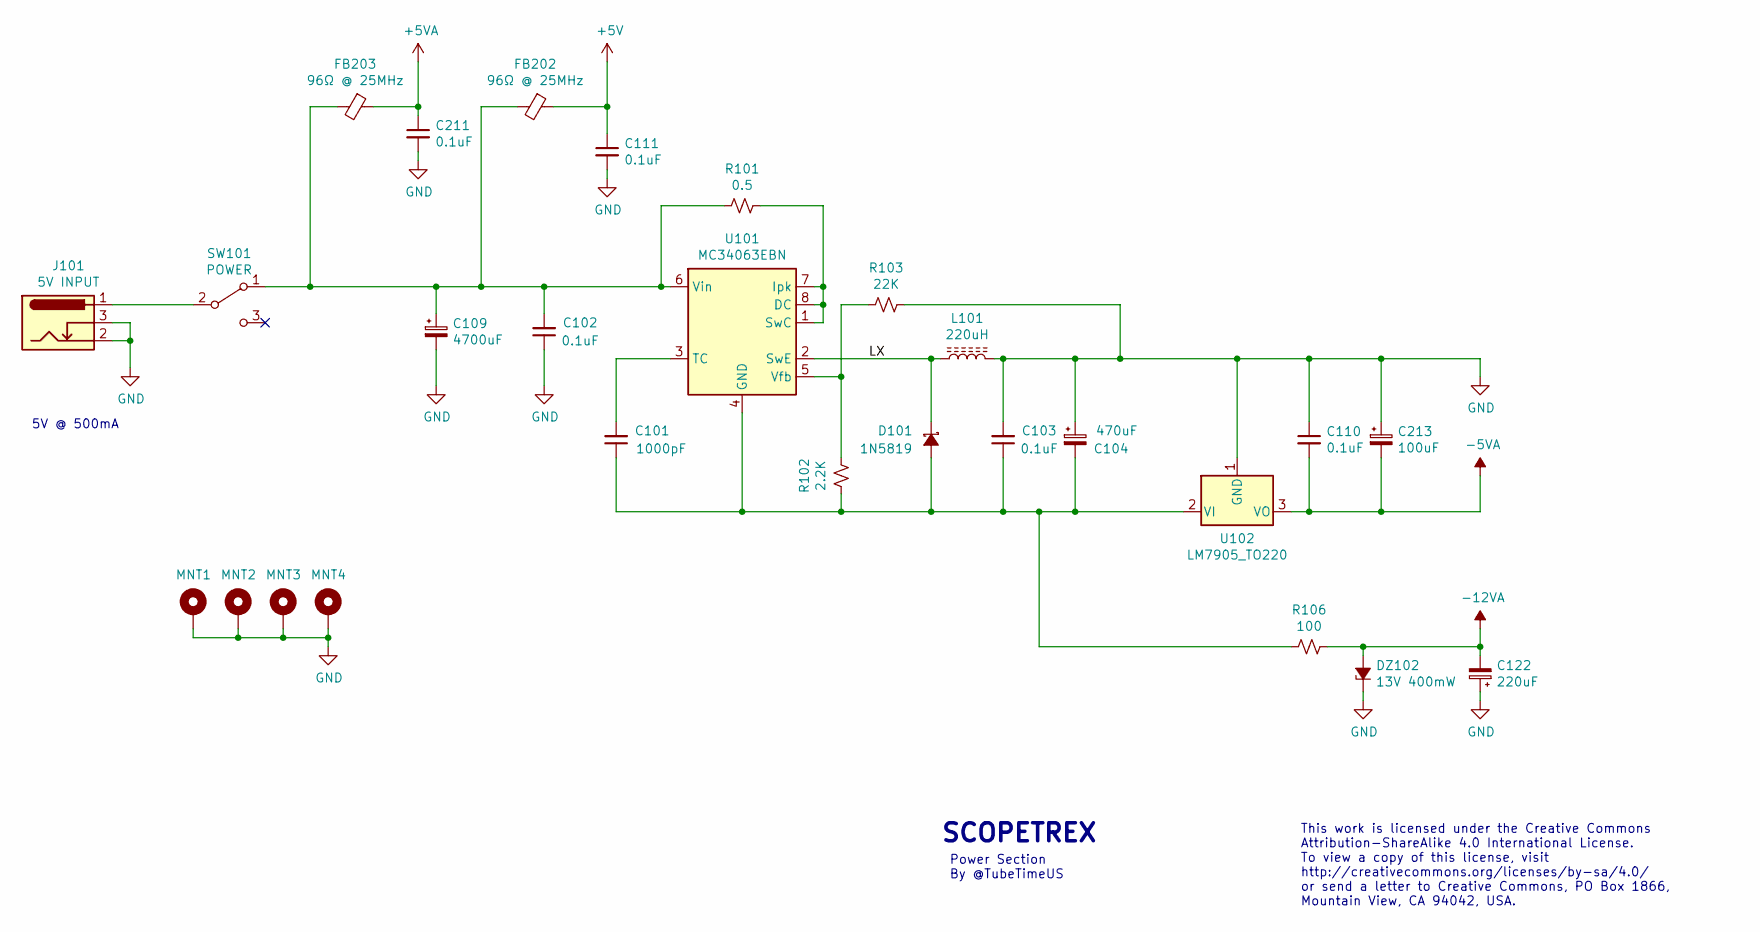
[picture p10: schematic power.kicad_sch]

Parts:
C101: 1000pF; C_Disc_D0.2in_W0.1in_P0.2in; Mouser 581-SR211A102JAR
C102, C103, C110, C111, C211: 0.1uF; C_Disc_D0.2in_W0.1in_P0.2in; Mouser 581-SR215C104K
C104: 470uF; CAPAE500P1000X1500; Mouser 80-ESL477M025AH9AA
C109: 4700uF; CAPAE750P1600X2500; Mouser 667-EEU-FS1C472S
C122: 220uF; CAPAE250P630X1100; Mouser 647-UVY1E221MED1TD
C213: 100uF; CAPAE200P500X1100; Mouser 647-UVY1E101MDD1TD
D101: 1N5819; DIOA500; Mouser 511-1N5819
DZ102: 13V 400mW; DIOA500; Mouser 512-1N4743ATR
FB202, FB203: 96Ω @ 25MHz; FB254; Mouser 623-2743007112
J101: 5V INPUT; CUI_PJ-002B; Mouser 490-PJ-002B
L101: 220uH; INDA500P780X750; Mouser 851-RCR875DNP-221K
MNT1, MNT2, MNT3, MNT4: MountingHole_Pad; MountingHole_3.5mm_Pad
R101: 0.5; RESA500; Mouser 660-CF1/4CR50J
R102: 2.2K; RESA500; Mouser 603-CFR-25JR-522K2
R103: 22K; RESA500; Mouser 603-CFR-25JR-5222K
R106: 100; RESA500; Mouser 603-CFR-25JR-52100R
SW101: POWER; NKK_CS12ANW03; Mouser 633-CS12ANW03
U101: MC34063EBN; DIP254P762X635-8; Mouser 511-MC34063EBN
U102: LM7905_TO220; TO-220-3_Vertical; Mouser 926-LM7905CT/NOPB

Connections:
+5V: C111.1, FB202.1; also elsewhere on the board
+5VA: C211.1, FB203.1; also elsewhere on the board
-5VA: C110.2, C213.2, U102.3 (VO); also elsewhere on the board
-12VA: C122.2, DZ102.2 (A), R106.1; also elsewhere on the board
/power/LX: D101.1 (K), L101.1, U101.2 (SwE)
GND: C102.1, C103.2, C104.1, C109.2, C110.1, C111.2, C122.1, C211.2, C213.1, DZ102.1 (K), J101.2, J101.3, L101.2, MNT1.1, MNT2.1, MNT3.1, MNT4.1, R103.1, U102.1 (GND); also elsewhere on the board
unnamed: C101.1, C103.1, C104.2, D101.2 (A), R102.2, R106.2, U101.4 (GND), U102.2 (VI)
unnamed: C101.2, U101.3 (TC)
unnamed: C102.2, C109.1, FB202.2, FB203.2, R101.2, SW101.1 (A), U101.6 (Vin)
unnamed: J101.1, SW101.2 (B)
unnamed: R101.1, U101.1 (SwC), U101.7 (Ipk), U101.8 (DC)
unnamed: R102.1, R103.2, U101.5 (Vfb)

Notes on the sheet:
Power Section By @TubeTimeUS
This work is licensed under the Creative Commons Attribution-ShareAlike 4.0 International License. To view a copy of this license, visit http://creativecommons.org/licenses/by-sa/4.0/ or send a letter to Creative Commons, PO Box 1866, Mountain View, CA 94042, USA.
SCOPETREX
5V @ 500mA

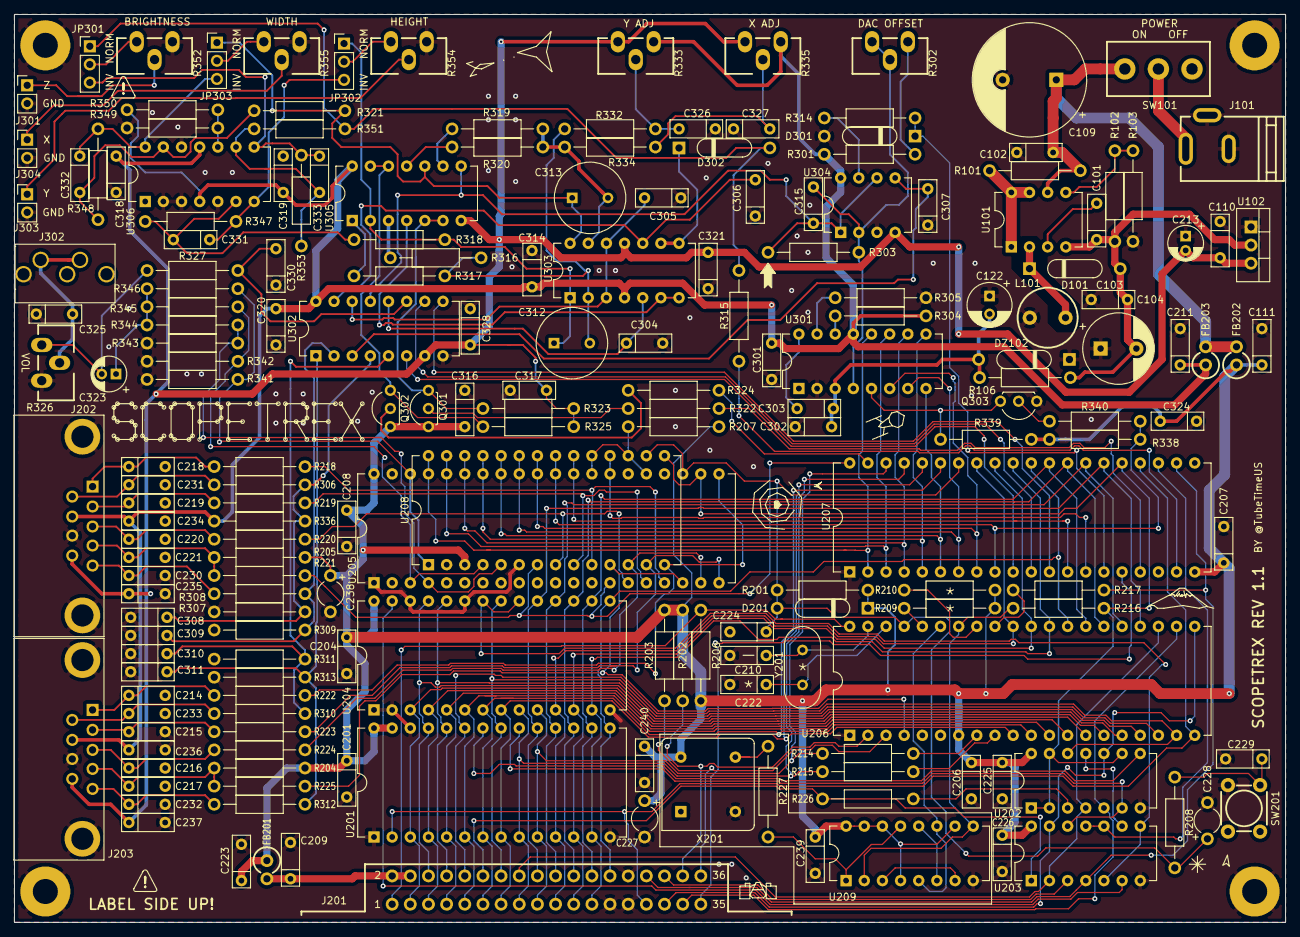
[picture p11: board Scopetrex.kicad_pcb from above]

Board: 2 copper layers, 177.8 x 127.0 mm, 201 parts (0 on the bottom side), 159 nets.

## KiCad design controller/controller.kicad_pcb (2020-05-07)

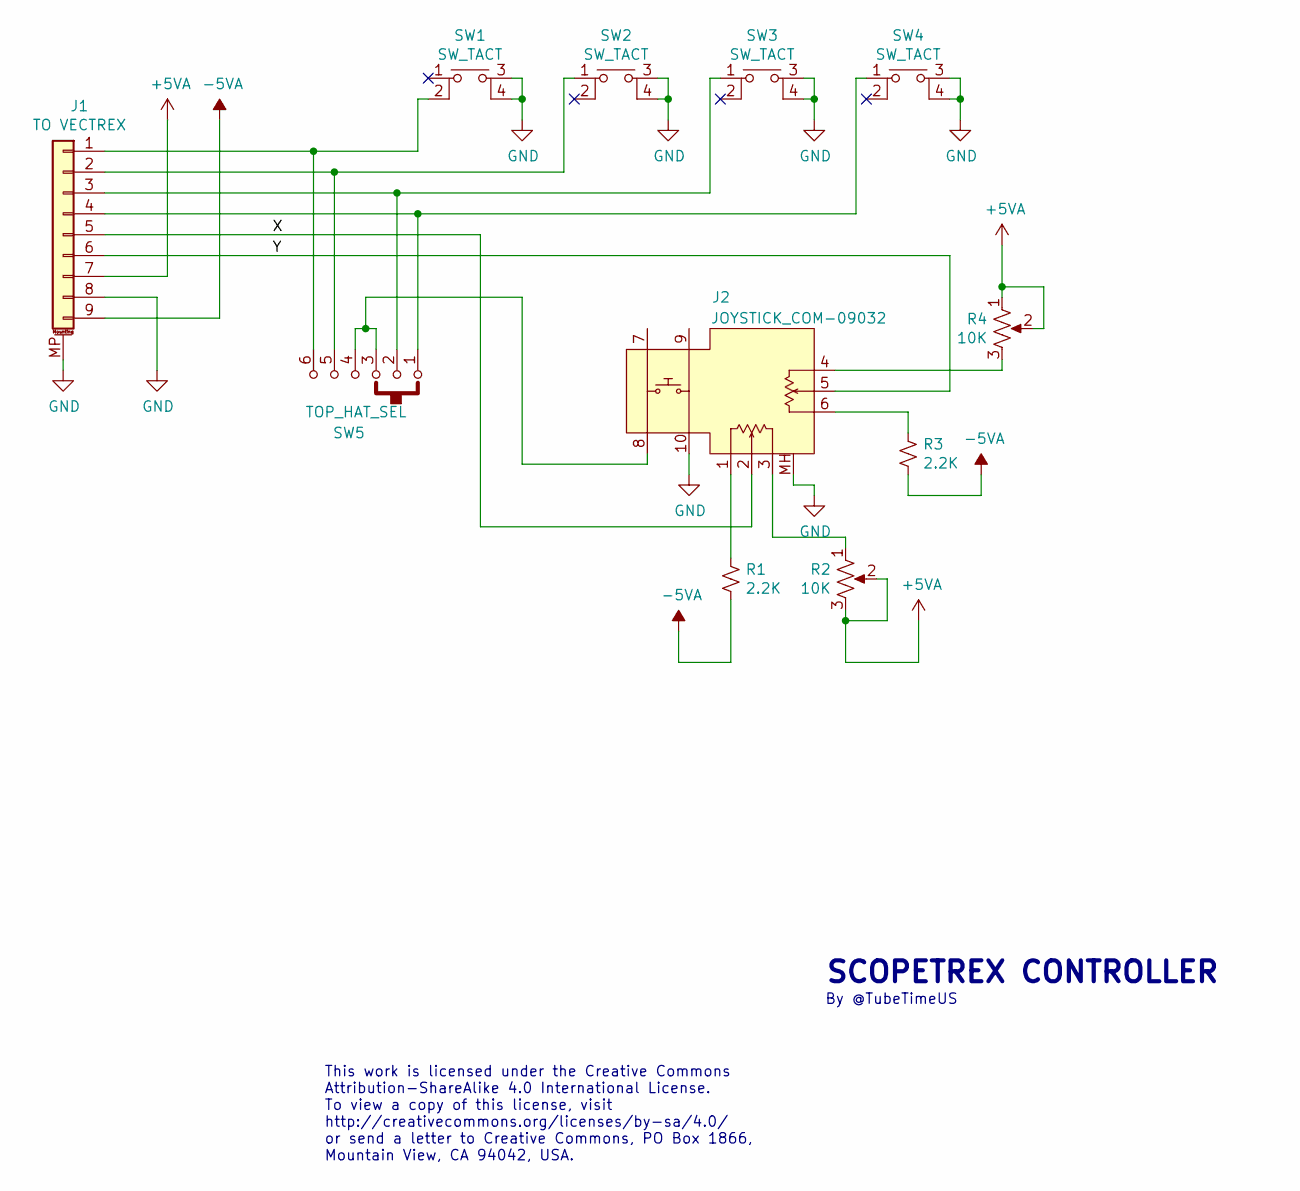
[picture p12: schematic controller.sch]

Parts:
J1: TO VECTREX; DB9FC2; Mouser 806-K22X-E9S-NR
J2: JOYSTICK_COM-09032; Digikey 1568-1526-ND
R1, R3: 2.2K; RESA500; Mouser 603-CFR-25JR-522K2
R2, R4: 10K; PIHER_PT10_V10; Mouser 531-PT10LV113A22PMS
SW1, SW2, SW3, SW4: SW_TACT; ALPS_SKHC; Mouser 688-SKHCBKA010
SW5: TOP_HAT_SEL; CK_SK-14D01-G-6; Mouser 611-SK-14D01-G6

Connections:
+5VA: J1.7, R2.2, R2.3, R4.1, R4.2
-5VA: J1.9, R1.2, R3.2
/X: J1.5, J2.2 (X2)
/Y: J1.6, J2.5 (Y2)
GND: J1.8, J1.MP (MountPin), J2.10 (SW2B), J2.MH, SW1.3, SW1.4, SW2.3, SW2.4, SW3.3, SW3.4, SW4.3, SW4.4, SW5.7 (GND)
unnamed: J1.1, SW1.2, SW5.6
unnamed: J1.2, SW2.1, SW5.5
unnamed: J1.3, SW3.1, SW5.2
unnamed: J1.4, SW4.1, SW5.1
unnamed: J2.1 (X1), R1.1
unnamed: J2.3 (X3), R2.1
unnamed: J2.4 (Y1), R4.3
unnamed: J2.6 (Y3), R3.1
unnamed: J2.8 (SW1B), SW5.3, SW5.4

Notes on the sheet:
This work is licensed under the Creative Commons Attribution-ShareAlike 4.0 International License. To view a copy of this license, visit http://creativecommons.org/licenses/by-sa/4.0/ or send a letter to Creative Commons, PO Box 1866, Mountain View, CA 94042, USA.
SCOPETREX CONTROLLER
By @TubeTimeUS

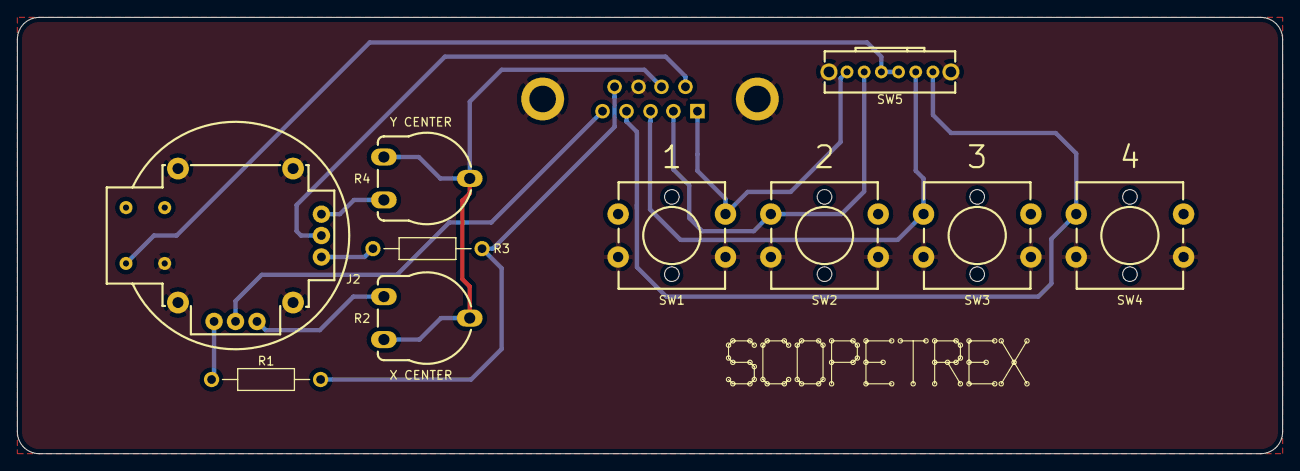
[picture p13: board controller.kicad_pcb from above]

Board: 2 copper layers, 147.3 x 50.8 mm, 11 parts (1 on the bottom side), 14 nets.

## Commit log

2020-05-07 Commit of rev 1.1 files
    [Scopetrex.kicad_pcb, Scopetrex.sch, Scopetrex_6809.csv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]
2020-05-07 Add schematic
2020-05-08 better part for right angle cart slot
    [Scopetrex.sch, Scopetrex_6809.csv, Scopetrex_6809E.csv]
2020-05-10 Fix FB201 value and change C238 to 22uF
    [Scopetrex.sch, Scopetrex_6809.csv, Scopetrex_6809E.csv]
2022-10-06 Correct Mouser part number for R103. Was 2K, should be 22K.
    [Scopetrex_6809.csv, Scopetrex_6809E.csv, power.sch]
2024-08-21 Fix interrupt line issue
    [Scopetrex.kicad_sch, Scopetrex.sch, analog.kicad_sch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]

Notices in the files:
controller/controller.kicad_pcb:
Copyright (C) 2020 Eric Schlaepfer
